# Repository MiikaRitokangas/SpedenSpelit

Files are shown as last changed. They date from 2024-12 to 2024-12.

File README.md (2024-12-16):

# SpedenSpelit

**WORK IN PROGRESS**

## Table of contensts

- [Project's goals](#projects-goals)
- [Project's topic – SpedenSpelit](#projects-topic--speden-spelit)
- [Additional features](#additional-features)
- [Technical Specifications](#technical-specifications)
- [List of components used](#list-of-components-used)
- [Case](#case)
- [Simulation](#simulation)

## Project's goals

The goal of the project is to implement a microprocessor application that monitors its surroundings with the help of sensors, and controls the hardware connected to the microprocessor based on the signals from the sensors. With the addition of learn basic skills of project work and documentation.

## Project's topic – Speden Spelit

Speden Spelit Speed Test works as the project’s topic. The Speed Test was one of the games used during the airing of the Finnish game show Speden Spelit in the years of 1988–2002. The goal of the Speed Test is to hit the right button indicated by a flash of a light in time, while the speed of the required inputs increases.

## Additional features

During the development of the project, there have been added additional features to the game. The features include two additional game modes. These game modes are a "sequence memory mode" and a "blind mode". These modes can be accessed from the games start menu.

## Technical Specifications

**Circuit diagram**

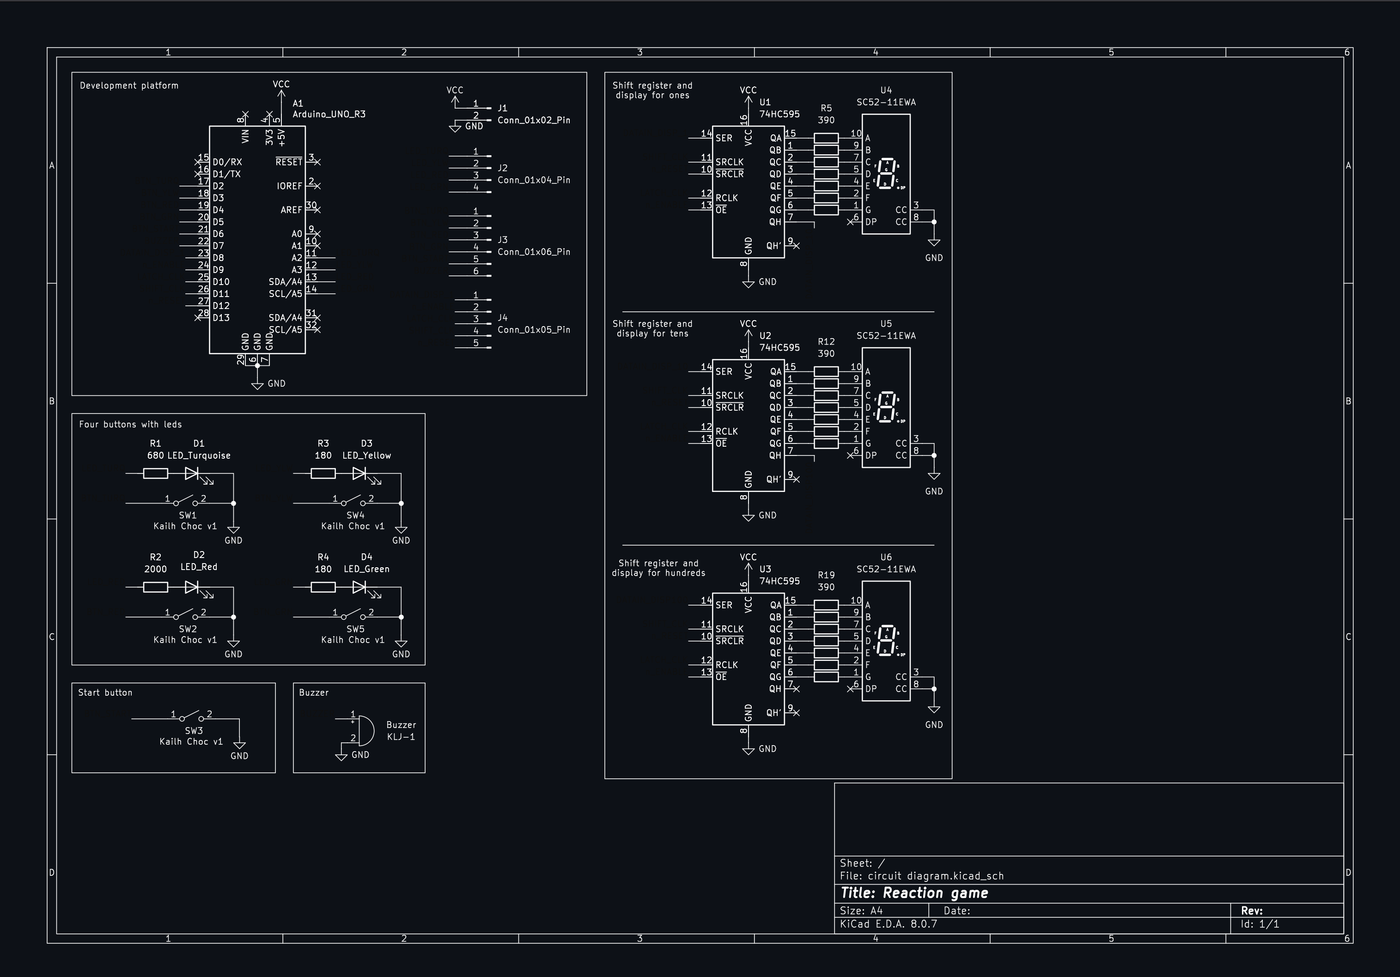
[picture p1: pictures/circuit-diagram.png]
Reaction-game-circuit-diagram


**Flowchart**

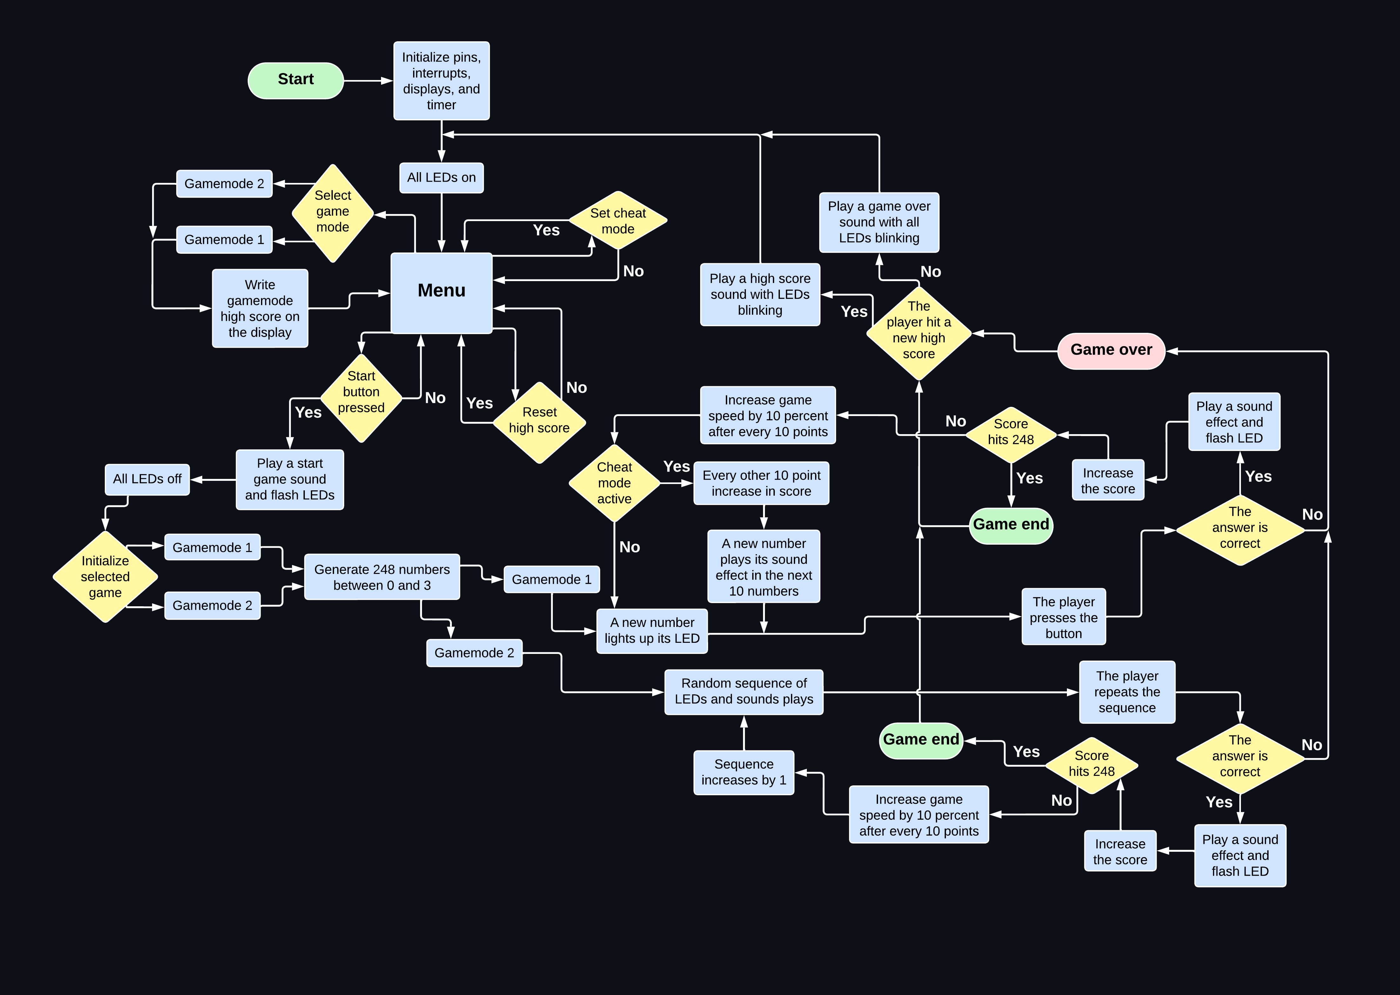
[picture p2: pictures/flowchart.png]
SpedenSpelit_Flowchart_5


## List of components used

| Type | Amount | Part model |
|---|---|---|
|Shift register | 3 | TI 74HC595N |
|7-segment display | 3 | Kingbright SA52-11EWA |
|Turquoise LED, Through Hole, 5mm | 1 | HLMP-4740 |
|Red LED, Through Hole, 5mm | 1 | Generic |
|Yellow LED, Through Hole, 5mm | 1 | Generic |
|Green LED, Through Hole, 5mm | 1 | Generic |
|SMD Piezo Buzzer | 1 | KLJ-1625 |
|Button switch | 5 | Kailh Choc v1 red |
|180 Ω resistor (yello and green LED) | 2 | Generic |
|680 Ω resistor (Turquoise LED) | 1 | Generic |
|390 Ω resistor (7-segment display) | 21 | Generic |
|2k Ω resistor (red LED) | 1 | Generic |

## Case

You can find the case .stl and .f3d files in the [/case-files](./case-files) folder
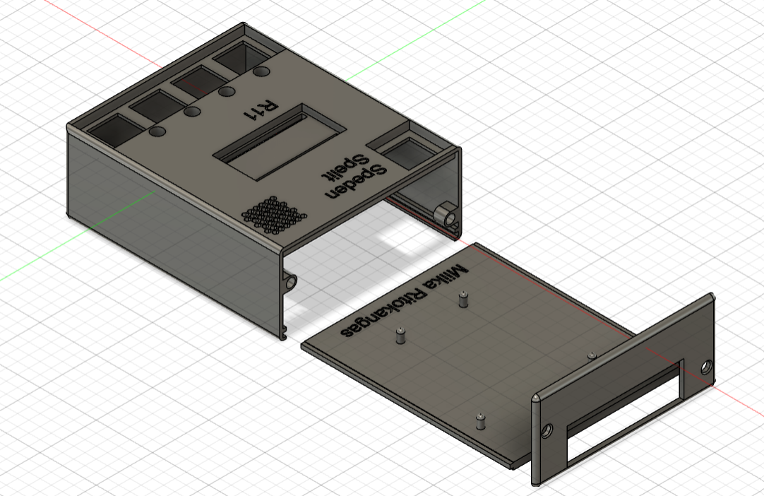
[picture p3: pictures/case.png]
Picture-of-the-case


## Simulation

You can simulate the game from wokwi [here](https://wokwi.com/projects/415181822807852033) or at https://wokwi.com/projects/415181822807852033.

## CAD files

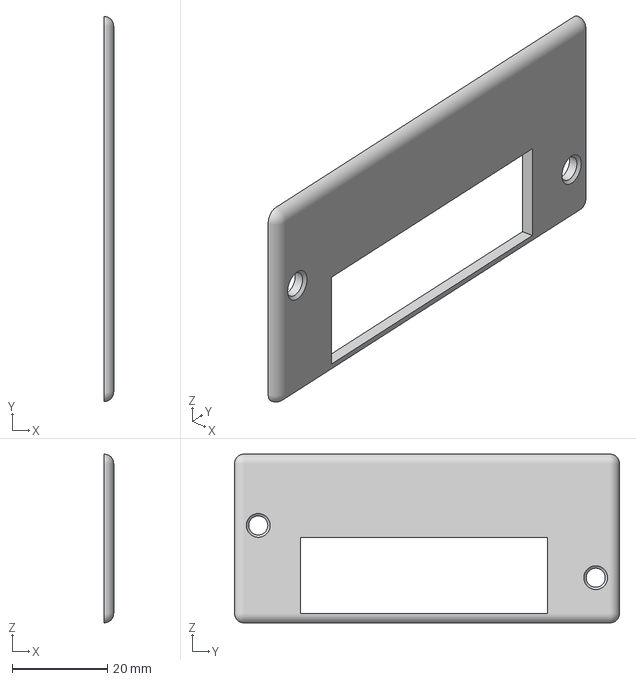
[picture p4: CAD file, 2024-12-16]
case-files/SpedSpel_case_final_topV3.3mf
2.00 x 81.0 x 35.5 mm

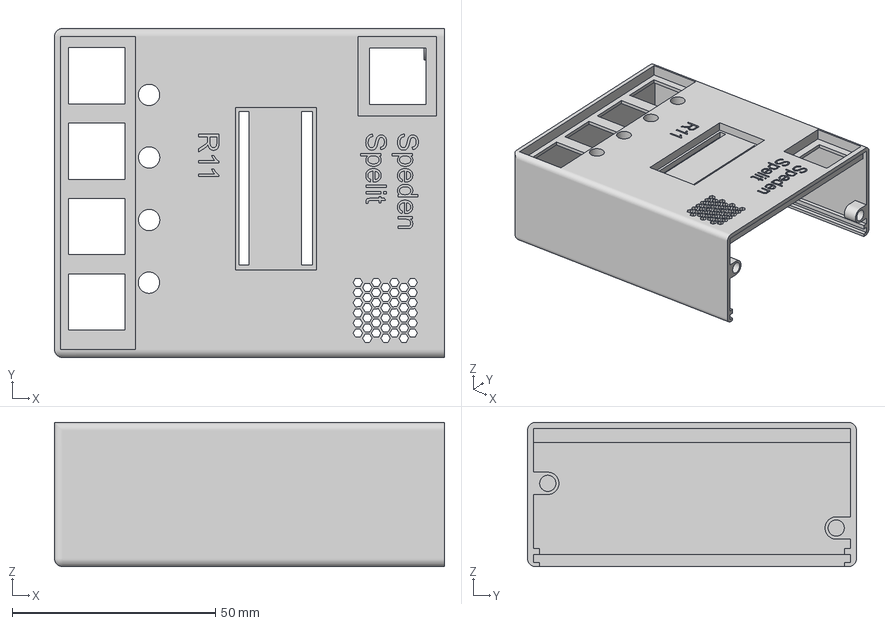
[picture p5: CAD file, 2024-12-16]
case-files/SpedSpel_case_final_body.3mf
96.0 x 81.0 x 35.5 mm

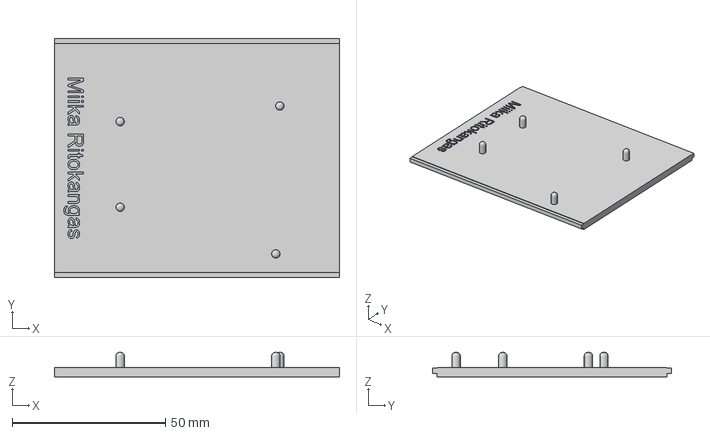
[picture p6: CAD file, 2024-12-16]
case-files/SpedSpel_case_final_bottomV2.3mf
93.0 x 78.0 x 8.00 mm

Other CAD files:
case-files/case_speden-spelit v5.f3d

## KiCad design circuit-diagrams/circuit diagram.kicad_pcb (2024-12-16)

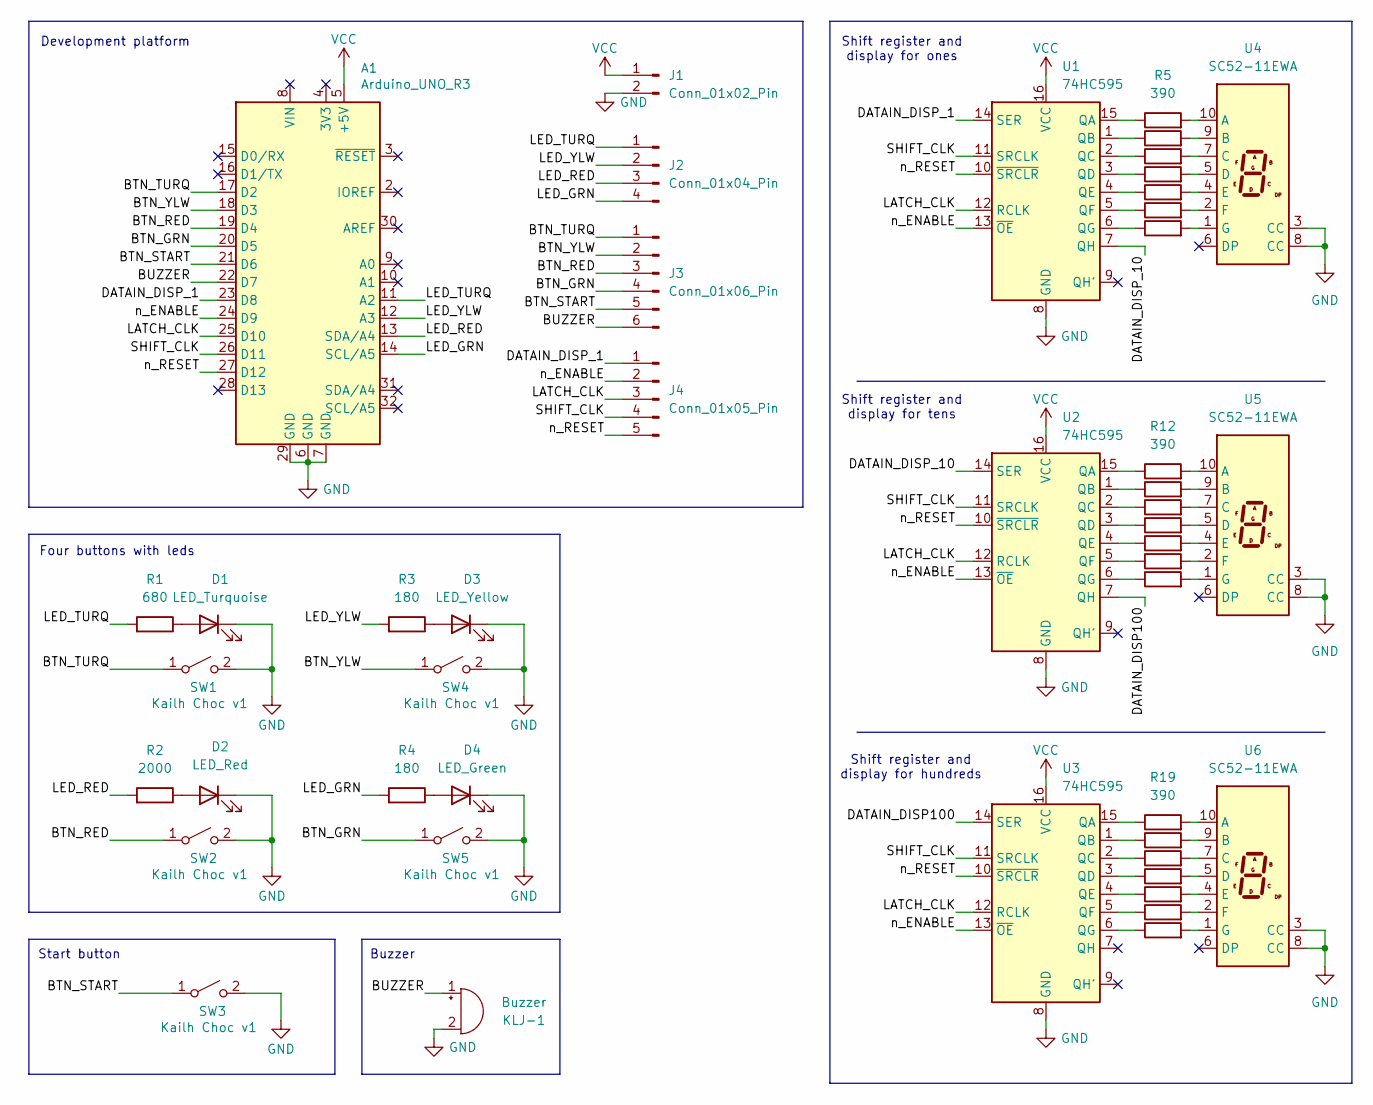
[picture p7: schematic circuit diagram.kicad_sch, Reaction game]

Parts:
A1: Arduino_UNO_R3
D1: LED_Turquoise; LED_D5.0mm
D2: LED_Red; LED_D5.0mm
D3: LED_Yellow; LED_D5.0mm
D4: LED_Green; LED_D5.0mm
J1: Conn_01x02_Pin; PinHeader_1x02_P2.54mm_Vertical
J2: Conn_01x04_Pin; PinHeader_1x04_P2.54mm_Vertical
J3: Conn_01x06_Pin; PinHeader_1x06_P2.54mm_Vertical
J4: Conn_01x05_Pin; PinHeader_1x05_P2.54mm_Vertical
KLJ-1: Buzzer; Piezo-KLJ-1625
R1: 680; R_Axial_DIN0207_L6.3mm_D2.5mm_P10.16mm_Horizontal
R2: 2000; R_Axial_DIN0207_L6.3mm_D2.5mm_P10.16mm_Horizontal
R3, R4: 180; R_Axial_DIN0207_L6.3mm_D2.5mm_P10.16mm_Horizontal
R5, R6, R7, R8, R9, R10, R11, R12, R13, R14, R15, R16, R17, R18, R19, R20, R21, R22, R23, R24, R25: 390; R_Axial_DIN0207_L6.3mm_D2.5mm_P10.16mm_Horizontal
SW1, SW2, SW3, SW4, SW5: Kailh Choc v1; SW_PG1350
U1, U2, U3: 74HC595; DIP-16_W7.62mm_Socket_LongPads
U4, U5, U6: SC52-11EWA; 7SegmentLED_LTS6760_LTS6780

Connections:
/BTN_GRN: A1.20 (D5), J3.4, SW5.1 (A)
/BTN_RED: A1.19 (D4), J3.3, SW2.1 (A)
/BTN_START: A1.21 (D6), J3.5, SW3.1 (A)
/BTN_TURQ: A1.17 (D2), J3.1, SW1.1 (A)
/BTN_YLW: A1.18 (D3), J3.2, SW4.1 (A)
/BUZZER: A1.22 (D7), J3.6, KLJ-1.1 (+)
/DATAIN_DISP100: U2.7 (QH), U3.14 (SER)
/DATAIN_DISP_1: A1.23 (D8), J4.1, U1.14 (SER)
/DATAIN_DISP_10: U1.7 (QH), U2.14 (SER)
/LATCH_CLK: A1.25 (D10), J4.3, U1.12 (RCLK), U2.12 (RCLK), U3.12 (RCLK)
/LED_GRN: A1.14 (SCL/A5), J2.4, R4.2
/LED_RED: A1.13 (SDA/A4), J2.3, R2.2
/LED_TURQ: A1.11 (A2), J2.1, R1.2
/LED_YLW: A1.12 (A3), J2.2, R3.2
/SHIFT_CLK: A1.26 (D11), J4.4, U1.11 (SRCLK), U2.11 (SRCLK), U3.11 (SRCLK)
/n_ENABLE: A1.24 (D9), J4.2, U1.13 (~OE), U2.13 (~OE), U3.13 (~OE)
/n_RESET: A1.27 (D12), J4.5, U1.10 (~SRCLR), U2.10 (~SRCLR), U3.10 (~SRCLR)
GND: A1.6 (GND), A1.7 (GND), A1.29 (GND), D1.1 (K), D2.1 (K), D3.1 (K), D4.1 (K), J1.2, KLJ-1.2 (-), SW1.2 (B), SW2.2 (B), SW3.2 (B), SW4.2 (B), SW5.2 (B), U1.8 (GND), U2.8 (GND), U3.8 (GND), U4.3 (CC), U4.8 (CC), U5.3 (CC), U5.8 (CC), U6.3 (CC), U6.8 (CC)
unnamed: D1.2 (A), R1.1
unnamed: D2.2 (A), R2.1
unnamed: D3.2 (A), R3.1
unnamed: D4.2 (A), R4.1
unnamed: R5.1, U1.15 (QA)
unnamed: R6.1, U1.1 (QB)
unnamed: R7.1, U1.2 (QC)
unnamed: R8.1, U1.3 (QD)
unnamed: R9.1, U1.4 (QE)
unnamed: R10.1, U1.5 (QF)
unnamed: R11.1, U1.6 (QG)
unnamed: R12.1, U2.15 (QA)
unnamed: R13.1, U2.1 (QB)
unnamed: R14.1, U2.2 (QC)
unnamed: R15.1, U2.3 (QD)
unnamed: R16.1, U2.4 (QE)
unnamed: R17.1, U2.5 (QF)
unnamed: R18.1, U2.6 (QG)
unnamed: R19.1, U3.15 (QA)
unnamed: R20.1, U3.1 (QB)
unnamed: R21.1, U3.2 (QC)
unnamed: R22.1, U3.3 (QD)
unnamed: R23.1, U3.4 (QE)
unnamed: R24.1, U3.5 (QF)
unnamed: R25.1, U3.6 (QG)
unnamed: R5.2, U4.10 (A)
unnamed: R6.2, U4.9 (B)
unnamed: R7.2, U4.7 (C)
unnamed: R8.2, U4.5 (D)
unnamed: R9.2, U4.4 (E)
unnamed: R10.2, U4.2 (F)
unnamed: R11.2, U4.1 (G)
unnamed: R12.2, U5.10 (A)
unnamed: R13.2, U5.9 (B)
unnamed: R14.2, U5.7 (C)
unnamed: R15.2, U5.5 (D)
unnamed: R16.2, U5.4 (E)
unnamed: R17.2, U5.2 (F)
unnamed: R18.2, U5.1 (G)
unnamed: R19.2, U6.10 (A)
unnamed: R20.2, U6.9 (B)
unnamed: R21.2, U6.7 (C)
unnamed: R22.2, U6.5 (D)
unnamed: R23.2, U6.4 (E)
unnamed: R24.2, U6.2 (F)
unnamed: R25.2, U6.1 (G)
VCC: A1.5 (+5V), J1.1, U1.16 (VCC), U2.16 (VCC), U3.16 (VCC)

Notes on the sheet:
Start button
Buzzer
Shift register and display for hundreds
Shift register and display for ones
Shift register and display for tens
Development platform
Four buttons with leds

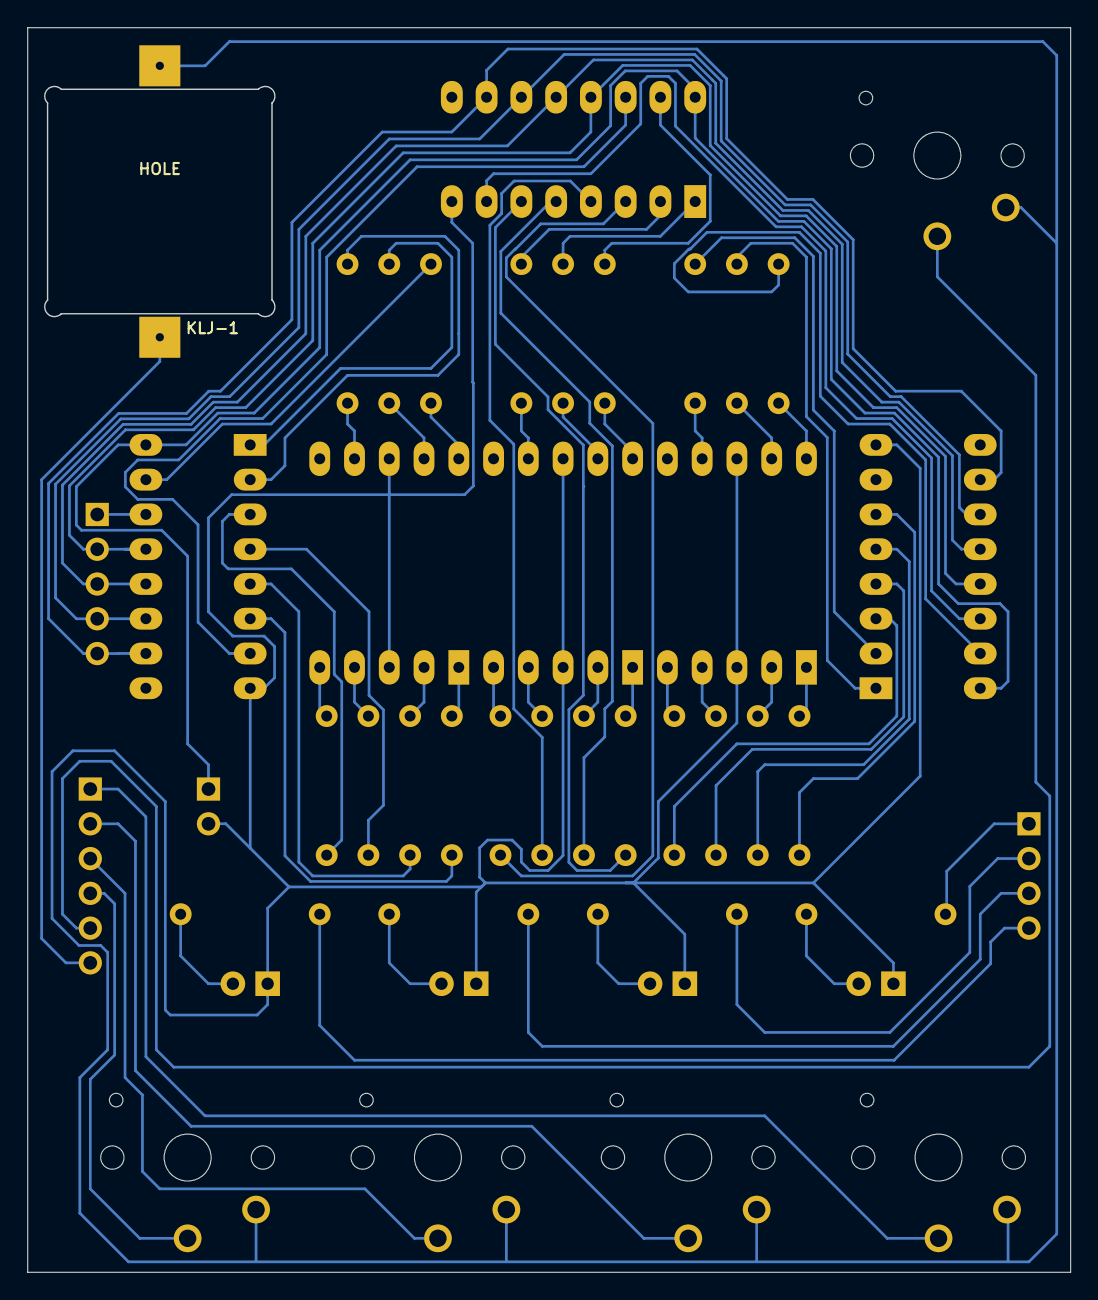
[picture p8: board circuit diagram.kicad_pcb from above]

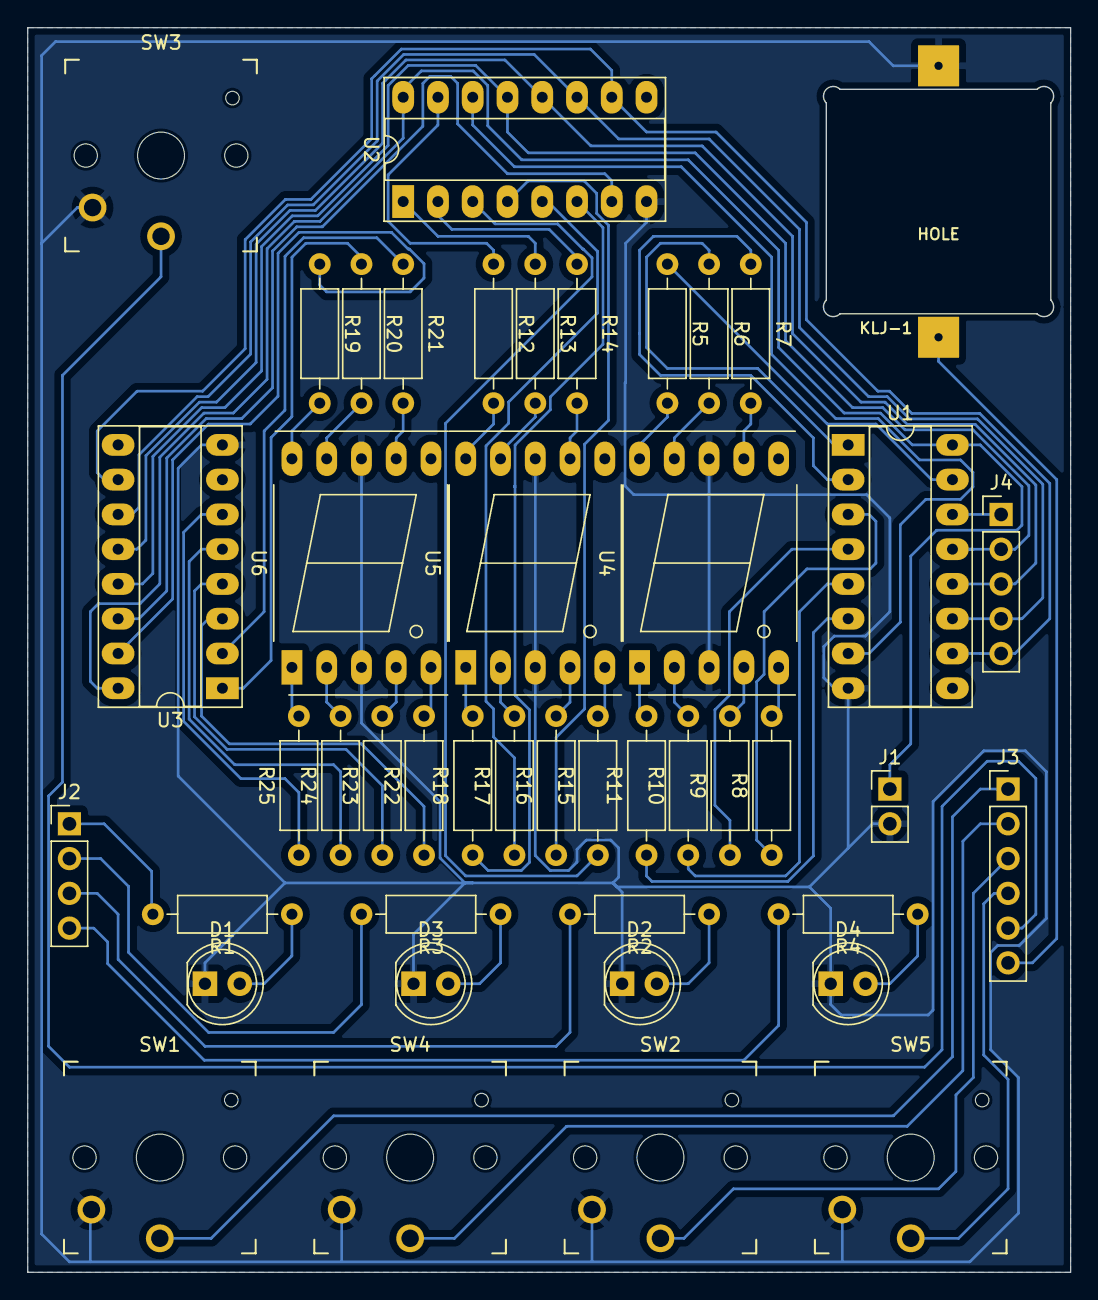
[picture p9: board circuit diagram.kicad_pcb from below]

Board: 2 copper layers, 76.2 x 90.9 mm, 45 parts (45 on the bottom side), 65 nets.

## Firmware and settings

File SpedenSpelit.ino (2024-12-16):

#include "SpedenSpelit.h"

// used for communicating between loop() and interrupts
volatile int buttonNumber = -1;           // for buttons interrupt handler
volatile bool newtimerInterrupt = false;  // for game.timer interrupt handler

extern gameStruct game = { MAINMENU, -1, 0, {}, 0, readHighscore(MODE1), readHighscore(MODE2), 0, false, 1.0, false };  // TODO implement high score fetching (EEPROM.read(0) << 8) + EEPROM.read(1)

int buttonNotes[4] = { TURQOISE_NOTE, YELLOW_NOTE, RED_NOTE, GREEN_NOTE };

void setup() {
  // Initializing all modules here
  Serial.begin(9600);
  initButtonsAndButtonInterrupts();
  initializeDisplay();
  initializeLeds();
  initializeBuzzer();
  initializetimer();
  interrupts();
}

void loop() {
  // check what state the game is in and call the correct function to handle the state.
  if (game.state == GAME && buttonNumber != -1 && buttonNumber != 4) {
    checkGame(buttonNumber);
    buttonNumber = -1;
  }
  switch (game.state) {
    case MAINMENU:
      handleMenu();
      break;
    case GAME:
      switch (game.mode) {
        case MODE1:
          game1Logic();
          break;
        case MODE2:
          game2Logic();
          break;
      }
      break;
    case STARTGAME:
      startGame();
      break;
    case STOPGAME:
      stopGame();
      break;
  }
}

long calculateFrequency(void) {
  return 1000000 * game.frequency;
}

void Timer1_ISR(void) {
  newtimerInterrupt = true;
}

void initializetimer(void) {
  // see requirements for the function from SpedenSpelit.h
  Timer1.initialize(1000000);
  Timer1.attachInterrupt(Timer1_ISR);
}

void checkGame(int userInput) {
  // check if the last played button was correct
  if (game.score < 250) {
    switch (game.mode) {
      case MODE1:
        if (game.values[game.score] == userInput) {
          setLed(userInput);
          if (!game.cheat) {
            playSound(buttonNotes[userInput], 4);
          }
          delay(250);
          clearAllLeds();
          game.score++;
          showResult(game.score);
        } else {
          game.state = STOPGAME;
        }
        break;
      case MODE2:
        if (game.waitForUserInput) {
          if (game.index <= game.score) {
            if (game.values[game.index] == userInput) {
              setLed(userInput);
              playSound(buttonNotes[userInput], 4);
              delay(250);
              clearAllLeds();
              game.index++;
            } else {
              game.state = STOPGAME;
            }
            if (game.score < game.index) {
              game.index = 0;
              game.score++;
              showResult(game.score);
              delay(1000);
              game.waitForUserInput = false;
            }
          }
        }
        break;
    }
  } else {
    game.state = STOPGAME;
  }
}

void handleMenu() {
  setAllLeds();
  switch (buttonNumber) {
    case 0:
      game.mode = MODE1;
      playSound(buttonNotes[buttonNumber], 4);
      flashLedMenu(buttonNumber);
      showResult(game.highScore1);
      buttonNumber = -1;
      break;
    case 1:
      game.mode = MODE2;
      playSound(buttonNotes[buttonNumber], 4);
      flashLedMenu(buttonNumber);
      showResult(game.highScore2);
      buttonNumber = -1;
      break;
    case 2:
      playSound(buttonNotes[buttonNumber], 4);
      flashLedMenu(buttonNumber);
      game.cheat = !game.cheat;
      buttonNumber = -1;
      break;
    case 3:
      if (game.mode != -1) {
        clearHighscore(game.mode);
        playSound(buttonNotes[buttonNumber], 4);
        flashLedMenu(buttonNumber);
        switch (game.mode) {
          case MODE1:
            game.highScore1 = readHighscore(game.mode);
            break;
          case MODE2:
            game.highScore2 = readHighscore(game.mode);
            break;
        }
      }
      buttonNumber = -1;
      break;
    case 4:
      buttonNumber = -1;
      if (game.mode != -1) {
        game.state = STARTGAME;
      }
      break;
  }
}


void initializeGame() {
  int previousNum = -1;
  int currentNum;
  game.score = 0;
  game.index = 0;
  game.frequency = 1.0;
  game.timer = 0;
  Timer1.setPeriod(calculateFrequency());
  randomSeed(analogRead(A0));
  for (int i = 0; i < 250; i++) {
    do {
      currentNum = int(random(0, 4));
    } while (currentNum == previousNum);
    game.values[i] = currentNum;
    Serial.println(currentNum);
    previousNum = currentNum;
  }
  playTune(game.mode);
  game.state = GAME;
}

void startGame() {
  clearAllLeds();
  initializeGame();
  delay(1000);
  Timer1.start();
}

void game1Logic() {
  if (newtimerInterrupt) {
    if (game.index < 250) {
      if ((!game.cheat) || !(game.index % 20 >= 10 && game.index % 20 < 20)) {
        setLed(game.values[game.index]);
      }
      if (game.cheat) {
        playSound(buttonNotes[game.values[game.index]], 4);
      }
      delay(250);
      clearAllLeds();
      game.index++;
      if (game.timer > 9) {
        game.timer = 1;
        if (game.frequency != 0.1) {
          game.frequency -= 0.1;
        }
        playTune(SPEEDUP_TUNE);
        Timer1.setPeriod(calculateFrequency());
      } else {
        game.timer++;
      }
      if (game.index > game.score + 5) {
        stopGame();
      }
      newtimerInterrupt = false;
    }
  }
}

void game2Logic() {
  if (!game.waitForUserInput) {
    for (int i = 0; i <= game.score; i++) {
      playSound(buttonNotes[game.values[i]], 4);
      setLed(game.values[i]);
      delay(500 * game.frequency);
      clearAllLeds();
    }
    game.waitForUserInput = true;
    if (game.score % 10 == 0 && game.score != 0 && game.frequency != 0.1) {
      game.frequency -= 0.1;
      Timer1.setPeriod(calculateFrequency());
      playTune(SPEEDUP_TUNE);
    }
  }
}

void stopGame() {
  // game ended, handle saving high game.score and ending the game
  if (game.mode == MODE1 && game.score > game.highScore1 || game.mode == MODE2 && game.score > game.highScore2 || game.score == 99) {
    switch (game.mode) {
      case MODE1:
        game.highScore1 = game.score;
        writeHighscore(game.highScore1, MODE1);
        break;
      case MODE2:
        game.highScore2 = game.score;
        writeHighscore(game.highScore2, MODE2);
        break;
    }
    playTune(HIGHSCORE_TUNE);
  } else {
    playTune(GAMEOVER_TUNE);
  }
  game.mode = -1;
  Timer1.stop();
  game.state = MAINMENU;
}

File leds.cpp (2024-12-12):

#include "leds.h"

byte gameStartLeds[] { 0, 1, 1, 2, 1, 50, 3, 0 }; // LEDs for start game sound 50 = break
byte gameStartAltLeds[] { 1, 0, 2, 4, 3, 7}; // LEDs for start game alternative sound
byte gameOverLeds[] {14, 14, 14}; //  LEDs for game over sound
byte highScoreLeds[] {12, 10, 7, 5, 6, 5, 4, 3, 1, 2, 0, 50}; //  LEDs for high score sound
byte speedUpLeds[] {40, 40, 40};

//Intializes analog pins A2,A3,A4,A5 to be used as outputs.
void initializeLeds()
{
  // see requirements for this function from leds.h
  pinMode(LED_0, OUTPUT); // Pin A2
  pinMode(LED_1, OUTPUT); // Pin A3
  pinMode(LED_2, OUTPUT); // Pin A4
  pinMode(LED_3, OUTPUT); // Pin A5
}

// need a solution for blinking leds without using delay, for example, setting a flag for a led to be blinked once and handling it in the main loop() with millis
// Flash a single LED
void flashLed(int ledNumber) {
  setLed(ledNumber); // LED on
  delay(ledDuration);
  setLed(ledNumber);  // LED off
}

// Flash a single LED for menu operations
void flashLedMenu(int ledNumber) {
  setLed(ledNumber);   // LED on
  delay(ledOffDuration);
  setLed(ledNumber);   // LED off
}

// Toggle multiple LEDs on and off with delay
void toggleLeds(byte leds[], int count, int delayTime) {
  for (int i = 0; i < count; i++) {
    setLed(leds[i]);
  }
  delay(delayTime);
  for (int i = 0; i < count; i++) {
    setLed(leds[i]);
  }
}

// Handle specific LED patterns based on the note
void handleLeds(byte note, int ledDelay) {
  switch (note) {
    case 4: { // Binary 0011: Turn on LEDs 0 and 1
        byte leds[] = {0, 1};
        toggleLeds(leds, 2, ledDelay);
        break;
      }
    case 5: { // Binary 0101: Turn on LEDs 0 and 2
        byte leds[] = {0, 2};
        toggleLeds(leds, 2, ledDelay);
        break;
      }
    case 6: { // Binary 0110: Turn on LEDs 1 and 2
        byte leds[] = {1, 2};
        toggleLeds(leds, 2, ledDelay);
        break;
      }
    case 7: { // Binary 0111: Turn on LEDs 0, 1, 2
        byte leds[] = {0, 1, 2};
        toggleLeds(leds, 3, ledDelay);
        break;
      }
    case 8: { // Binary 1001: Turn on LEDs 0 and 3
        byte leds[] = {0, 3};
        toggleLeds(leds, 2, ledDelay);
        break;
      }
    case 9: { // Binary 1010: Turn on LEDs 1 and 3
        byte leds[] = {1, 3};
        toggleLeds(leds, 2, ledDelay);
        break;
      }
    case 10: { // Binary 1011: Turn on LEDs 0, 1, 3
        byte leds[] = {0, 1, 3};
        toggleLeds(leds, 3, ledDelay);
        break;
      }
    case 11: { // Binary 1100: Turn on LEDs 2 and 3
        byte leds[] = {2, 3};
        toggleLeds(leds, 2, ledDelay);
        break;
      }
    case 12: { // Binary 1101: Turn on LEDs 0, 2, 3
        byte leds[] = {0, 2, 3};
        toggleLeds(leds, 3, ledDelay);
        break;
      }
    case 13: { // Binary 1110: Turn on LEDs 1, 2, 3
        byte leds[] = {1, 2, 3};
        toggleLeds(leds, 3, ledDelay);
        break;
      }
    case 14: { // Binary 1111: Turn on all LEDs
        byte leds[] = {0, 1, 2, 3};
        toggleLeds(leds, 4, ledDelay);
        break;
      }
    default:
      if (note != 40) {
        setLed(note);   // Turn on a single LED
        delay(ledDelay);// Delay
        setLed(note);   // Turn off
      }
      break;
  }
}

// Set specific LED on/off.
// If the LED is off it will go on or if it's already on it will go off
void setLed(byte ledNumber)
{
  // see requirements for this function from leds.h
  //  LED 0
  if (ledNumber == 0) {
    int ledVal = digitalRead(LED_0);  //Read LED current value
    if (ledVal == HIGH) {
      digitalWrite(LED_0, LOW); // Set LED off
    }
    else {
      digitalWrite(LED_0, HIGH); // Set LED on
    }
  }
  //  LED 1
  if (ledNumber == 1) {
    int ledVal = digitalRead(LED_1);  //Read LED current value
    if (ledVal == HIGH) {
      digitalWrite(LED_1, LOW); // Set LED off
    }
    else {
      digitalWrite(LED_1, HIGH); // Set LED on
    }
  }
  //  LED 2
  if (ledNumber == 2) {
    int ledVal = digitalRead(LED_2);  //Read LED current value
    if (ledVal == HIGH) {
      digitalWrite(LED_2, LOW); // Set LED off
    }
    else {
      digitalWrite(LED_2, HIGH); // Set LED on
    }
  }
  //  LED 3
  if (ledNumber == 3) {
    int ledVal = digitalRead(LED_3);  //Read LED current value
    if (ledVal == HIGH) {
      digitalWrite(LED_3, LOW); // Set LED off
    }
    else {
      digitalWrite(LED_3, HIGH); // Set LED on
    }
  }
}

// Set all LEDs off
void clearAllLeds()
{
  // see requirements for this function from leds.h
  digitalWrite(LED_0, LOW); // Set LED 0 off
  digitalWrite(LED_1, LOW); // Set LED 1 off
  digitalWrite(LED_2, LOW); // Set LED 2 off
  digitalWrite(LED_3, LOW); // Set LED 3 off
}

// Set all LEDs on
void setAllLeds()
{
  // see requirements for this function from leds.h
  digitalWrite(LED_0, HIGH); // Set LED 0 on
  digitalWrite(LED_1, HIGH); // Set LED 1 on
  digitalWrite(LED_2, HIGH); // Set LED 2 on
  digitalWrite(LED_3, HIGH); // Set LED 3 on
}

// Shows numbers 0,1,...,15 as binary numbers
void show1()
{
  // see requirements for this function from leds.h
  // Loop for numbers 0-15
  for (int i = 0; i < 16; i++) {
    int number = i;
    byte numInBinary = 0;
    //  Loop for get binary from number
    for (byte b = 0; b < 4; b++) {
      numInBinary = bitRead(number, b); //  Read number as binary
      //  If the binary value is 1 set a specific LED on
      //  or if the binary value is 0 set specific LED off
      if (numInBinary == 1) {
        // Check what LED we need to set on
        switch (b) {
          case 0:
            digitalWrite(LED_0, HIGH);
            break;
          case 1:
            digitalWrite(LED_1, HIGH);
            break;
          case 2:
            digitalWrite(LED_2, HIGH);
            break;
          case 3:
            digitalWrite(LED_3, HIGH);
            break;
          default:
            break;
        }
      }
      else {
        // Check what LED we need to set off
        switch (b) {
          case 0:
            digitalWrite(LED_0, LOW);
            break;
          case 1:
            digitalWrite(LED_1, LOW);
            break;
          case 2:
            digitalWrite(LED_2, LOW);
            break;
          case 3:
            digitalWrite(LED_3, LOW);
            break;
          default:
            break;
        }
      }
    }
    // Delay between numbers
    delay(1250);
  }
  clearAllLeds();
}
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

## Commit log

2024-11-13 päivitetty buzzer ja aloitettu logiikan tekemistä
    [SpedenSpelit.ino, buttons.cpp]
2024-11-13 Leds module updated
2024-11-14 Added button debounce
2024-11-14 Added show2() to leds.cpp
2024-11-18 Adjusted button debounce
2024-11-20 kehitetty pelilogiikkaa ja buzzeria, korjattu bugeja
    [SpedenSpelit.ino]
2024-11-25 Added leds for game sounds
2024-12-01 Gamelogic updates and fixes, added first version of diagram.json for wokwi
    [SpedenSpelit.ino]
2024-12-01 unohdin stagettaa
2024-12-09 Added LED resistors
2024-12-09 Fixed game logic, added proper wokwi diagram, misc..
    [SpedenSpelit.ino, buttons.cpp, leds.cpp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]
2024-12-10 Fixed led issue in speedUpTune
    [leds.cpp, leds.h]
2024-12-10 Added circuit diagram
2024-12-10 Added a circuit diagram
2024-12-11 Update the circuit diagram
2024-12-12 Added case and circuit files to the project files
    [case_body.3mf, case_roof.3mf, circuit diagram.kicad_pcb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]
2024-12-12 Updated resistor values
2024-12-12 Minor adjustments
    [circuit diagram-B_Cu.gbr, circuit diagram-B_Silkscreen.gbr, circuit diagram-Edge_Cuts.gbr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]
2024-12-13 Added a flowchart
2024-12-15 removed old files and added the new case designs
    [SpedSpel_case_final_body.3mf, SpedSpel_case_final_bottomV2.3mf, SpedSpel_case_final_topV3.3mf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]
2024-12-15 korjattu bugi displaystä, laitettu peli kestämään 250 roundia
    [SpedenSpelit.ino, display.cpp]
2024-12-15 Added missing variable initialization
    [display.cpp]
